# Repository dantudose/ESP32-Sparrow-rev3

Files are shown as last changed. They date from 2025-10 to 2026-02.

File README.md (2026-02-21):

# ESP32-Sparrow rev.3 Board

The ESP32 Sparrow board is an IoT device designed for projects that require low battery consumption. It is built around the ESP32-C6 module, which features WiFi, Bluetooth, Zigbee and Thread communication.

## Pinout

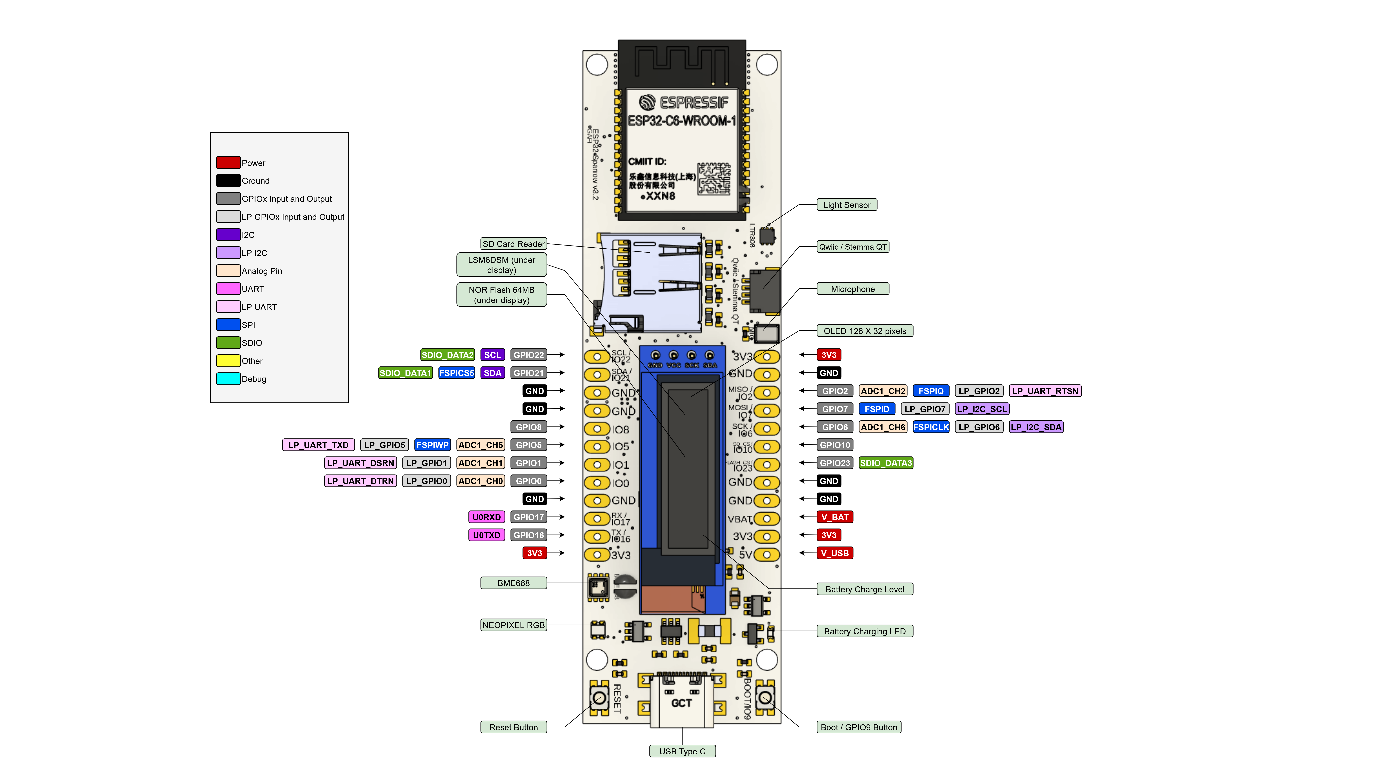
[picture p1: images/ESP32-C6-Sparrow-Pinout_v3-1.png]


## Components

- **Display:** 0.91" SSD1306 128x32 OLED (I2C)
- **Memory:** 
    - **Flash:** W25Q512JVEIQ - 64 MB Flash memory (SPI)
    - **SD card** slot for external storage (SPI)
- **Sensors:** 
    - **BME688**  - Temperature, humidity, pressure, and air quality sensor (I2C)
    - **SLSM6DSL** - 3-axis accelerometer and gyroscope (I2C)
    - **LTR303** - Ambient light sensor (I2C)
- **Microphone:** ICS-43434 - High-quality digital microphone (I2S)
- **LED:** WS2812B2020 - Neopixel RGB LED (GPIO)
- **Communication:** PRT-14417 - Qwiic/Stemma QT connector (I2C)
- **Voltage Supervisor:** BD5229G-TR - Shuts down microcontroller below 2.9V
- **Battery Level:** MAX17048 - Measures battery voltage (I2C)
- **USB C** connector for programming/charging
- **Power:** 18650 Battery - Holder on the back

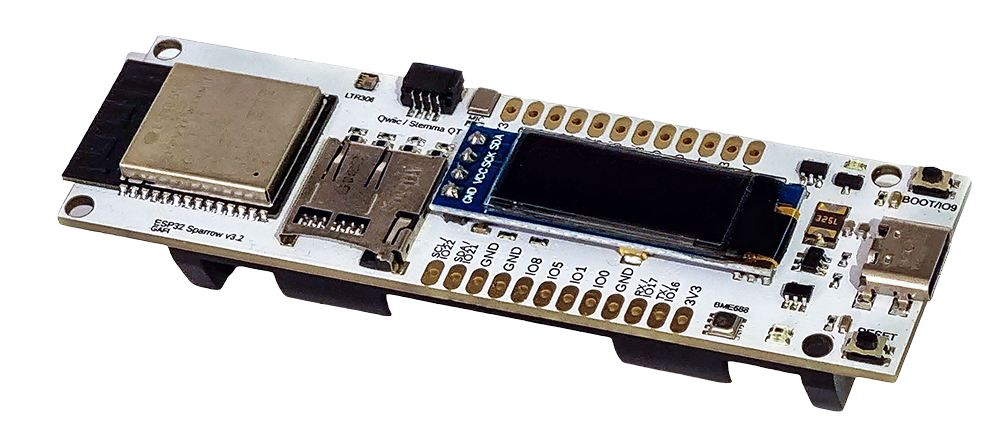
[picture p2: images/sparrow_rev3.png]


## Repository Contents
* **/hardware** - Fusion360 design files (.brd, .sch) and .pdf schematic
* **/images** - Pinout and board images
* **/software** - Code examples
    * **/arduino-ide** - Simple Arduino project
    * **/platformio** - Test project for PlatformIO
    * **/zephyr** - Test project for Zephyr OS

## Pins for each component

**1. MicroSD Card Holder (SPI)**

| PIN NAME | GPIO Pin |
|---|---|
| SD_CS | GPIO10 |
| MOSI | GPIO7 |
| MISO | GPIO2 |
| SCK | GPIO6 |

**2. NOR Flash (SPI)**

| PIN NAME | GPIO Pin |
|---|---|
| FLASH_CS | GPIO23 |
| MOSI | GPIO7 |
| MISO | GPIO2 |
| SCK | GPIO6 |

**3. I2C Sensors**

| PIN NAME | GPIO Pin |
|---|---|
| SCL | GPIO22 |
| SDA | GPIO21 |

**4. I2C Bus Addresses**

| CHIP | Address |
|---|---|
| LSM6DSL | 0x6A |
| BME680  | 0x76 |
| LTR303  | 0x29 |

**5. Neopixel RGB LED**

| PIN NAME | GPIO Pin |
|---|---|
| NEOPIXEL | GPIO3 |

**6. Microphone ICS-43434 (I2S)**

| PIN NAME | GPIO Pin |
|---|---|
| MIC_WS | GPIO20 |
| MIC_SCK  | GPIO18 |
| MIC_SD | GPIO19 |

**7. Battery Charge Level MAX17048**

| PIN NAME | GPIO Pin |
|---|---|
| INT_VLT  | GPIO4 |

**8. Other pins**

| PIN NAME | GPIO Pin |
|---|---|
| IO / BOOT Button | GPIO9 |
| UART_TX | GPIO16 |
| UART_RX | GPIO17 |
| Accelerometer Interrupt| GPIO11 |
| LTR303 Interrupt | GPIO15 |

License Information
-------------------

This product is _**open source**_! 

Please review the LICENSE file for license information. 

Distributed as-is; no warranty is given.

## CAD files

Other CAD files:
hardware/ESP32_C6_Sparrow.f3d

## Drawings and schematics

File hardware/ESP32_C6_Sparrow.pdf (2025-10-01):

# I2C OLED Display 128x32

D2

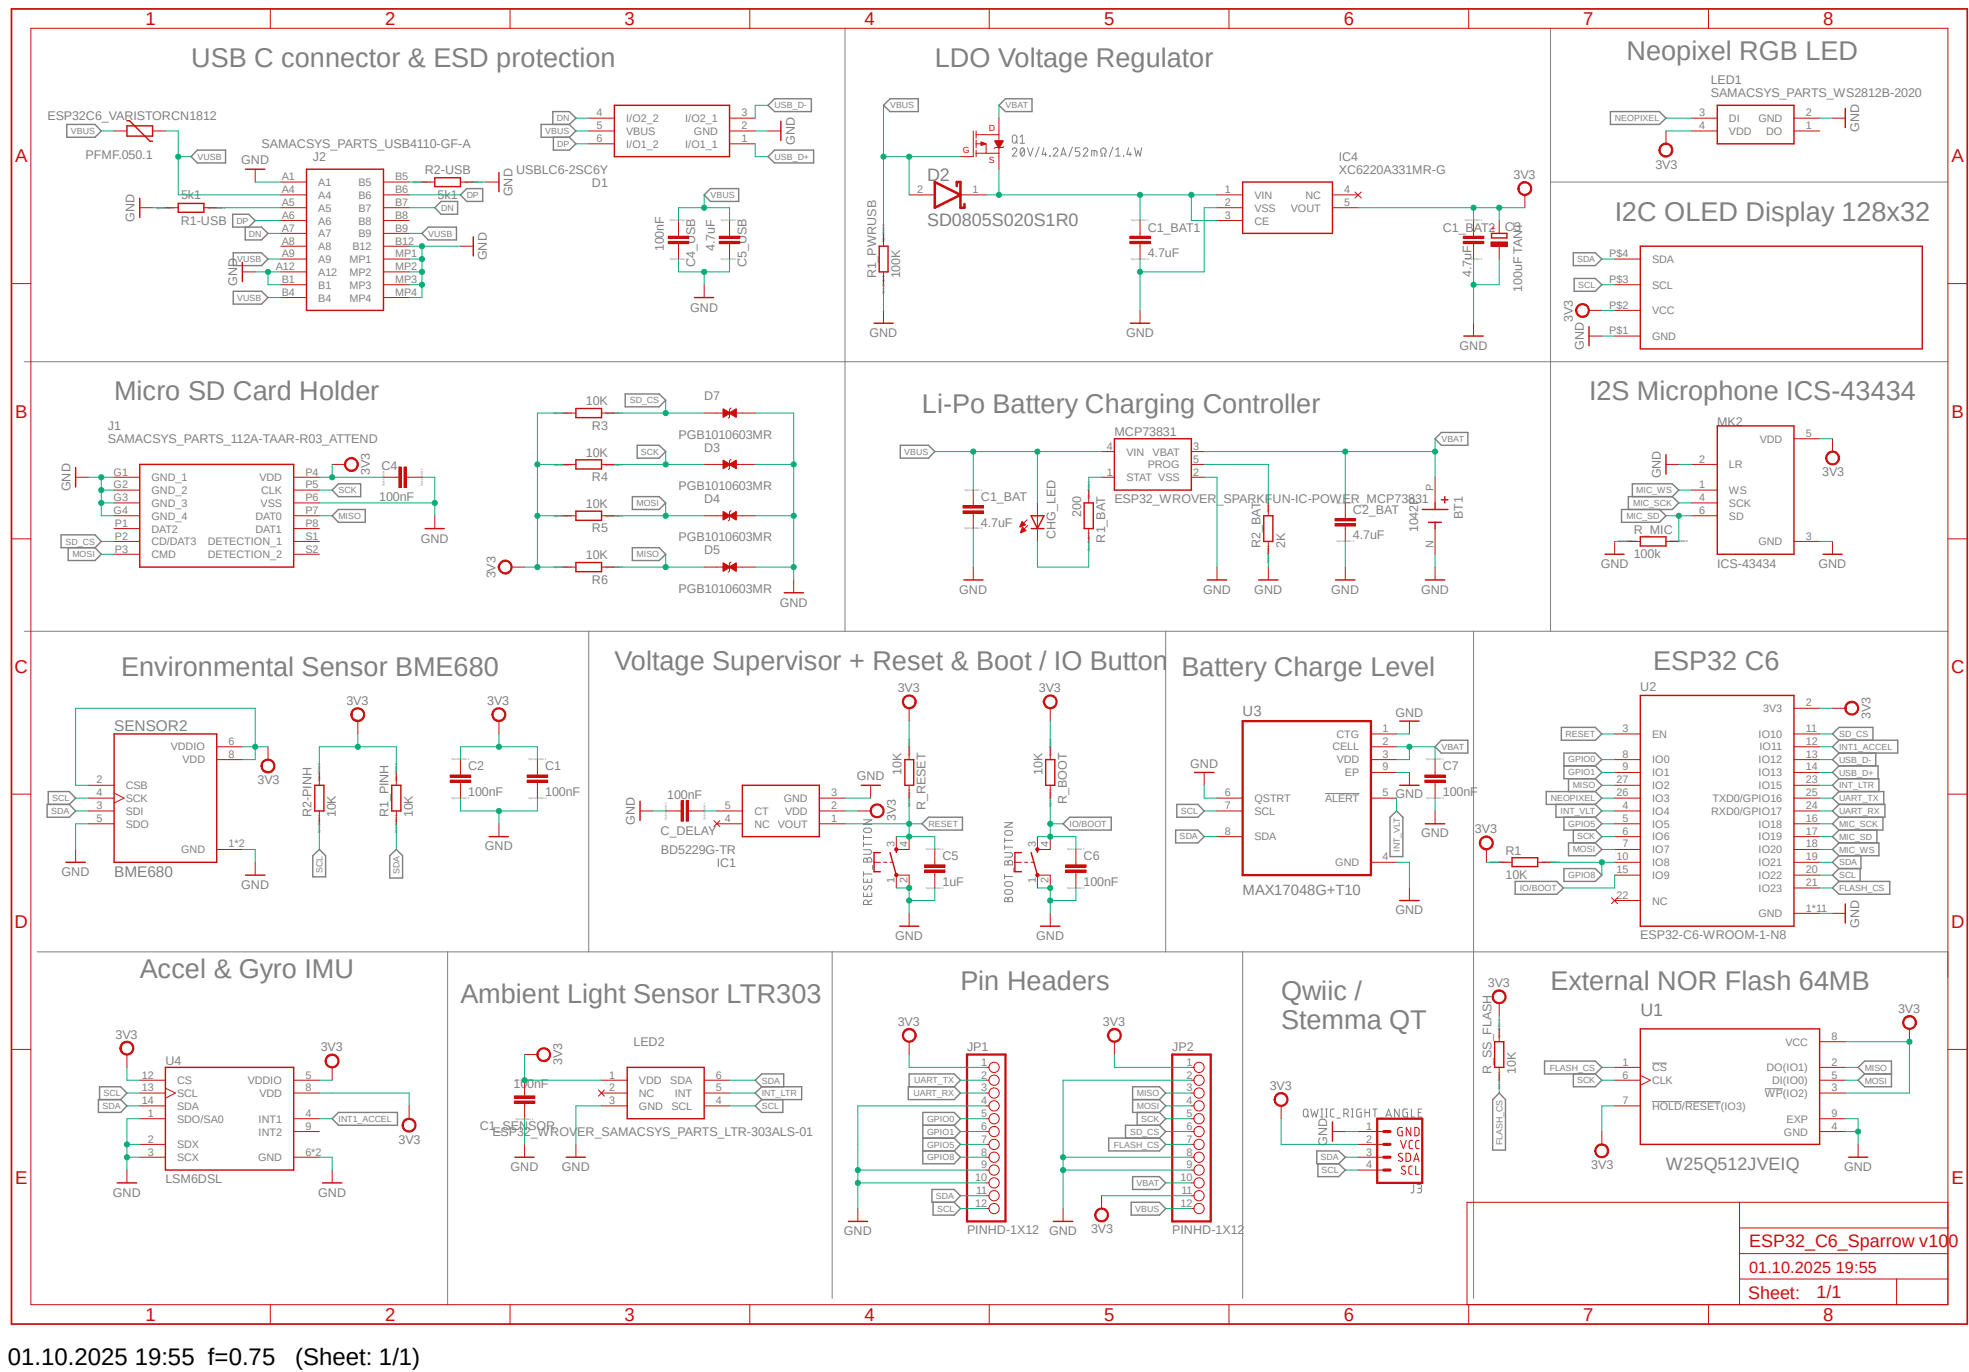
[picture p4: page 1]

USB C connector & ESD protection | LDO Voltage Regulator | Neopixel RGB LED LED1 SAMACSYS_PARTS_WS2812B-2020

Micro SD Card Holder

Li-Po Battery Charging Controller

Voltage Supervisor + Reset & Boot / IO Button

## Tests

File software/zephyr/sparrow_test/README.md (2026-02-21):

# Sparrow Test Project (Zephyr)

Minimal Zephyr application intended for the Sparrow v3.2 board (ESP32-C6-WROOM-1-N4, 4MB Flash).

## Build & Flash

From this folder:

```sh
west build -b esp32c6_devkitc/esp32c6/hpcore -p auto .
west flash -d build --runner esp32
```

## Connect over USB
```sh
screen /dev/cu.usbmodem1101 115200
```

## One-shot dev script

There is a helper script to clean, build, flash the LittleFS image, flash
firmware, and open a serial terminal:

```sh
./scripts/dev_flash.sh /dev/cu.usbmodem1101
```

Override the board with `BOARD=...` if needed.

## LittleFS assets

This app serves the all file assets directly into the LittleFS partition in the ESP32C6 internal Flash.

Build the image (requires `mklittlefs` in your PATH, run >brew install mklittlefs):

```sh
west build -t littlefs_image
```

Flash the image (overwrites `/lfs` contents, including logs):

```sh
ESPTOOL_PORT=/dev/tty.usbmodemXXXX python3 scripts/flash_littlefs_image.py --build-dir build
```

## Startup script

Files under `lfs/` are copied to the LittleFS root. If `lfs/startup.txt` is
present, the app executes each non-empty line as a shell command at boot.

Example `lfs/startup.txt`:

```txt
net iface up 1
wifi connect -s "WIFI_AP" -p "WIFI_PASSWORD" -k 1 -i 1
```

## Boot log

Boot and startup script events are logged to `/lfs/logs/boot.log`. You can read
it from the shell:

```sh
fs cat /lfs/logs/boot.log
```

## Features

This application includes a rich set of features for interacting with the Sparrow v3.2 hardware.

- **Peripherals**: Drivers and shell commands for the onboard OLED display, BME680, LSM6DSL, LTR303, MAX17048 sensors, and Neopixel.
- **Connectivity**: WiFi station mode with network time (NTP) synchronization.
- **Storage**: LittleFS filesystem on the internal flash for configuration, web assets, and data logging.
- **Remote Access**: A web-based UI and a comprehensive serial shell for control and diagnostics.
- **Automation**: A startup script (`/lfs/startup.txt`) can be used to run shell commands on boot.

## Peripherals

### OLED Display

The monochrome OLED display can be controlled via the `oled` shell command. It can display text, status information, and images.

- **Show status**: `oled status`
- **Show info screen**: `oled info 5` (updates every 5 seconds)
- **Turn display on/off**: `oled on`, `oled off`
- **Print text**: `oled print 0 0 "Hello"`
- **Draw a PBM image**: `oled bmp bitmaps/smiley.pbm`

The info screen provides a summary of the device status, including time, IP address, and sensor readings.

### Sensors

The application supports several onboard sensors, each with its own set of shell commands for configuration and data logging.

- **BME680 (Temp/Humidity/Pressure/Gas)**: `bme` command.
  - `bme read`: Read current sensor values.
  - `bme log start 30`: Start logging data every 30 seconds to `/lfs/logs/bme.csv`.
- **LSM6DSL (Accelerometer/Gyro)**: `lsm6dsl` command.
  - `lsm6dsl read`: Read current sensor values.
  - `lsm6dsl log start`: Start logging data.
- **LTR303 (Ambient Light)**: `ltr` command.
  - `ltr read`: Read current light sensor values (lux).
  - `ltr log start`: Start logging data.
- **MAX17048 (Fuel Gauge)**: `max` command.
  - `max read`: Read battery voltage and state of charge.
  - `max log start`: Start logging battery status.

### Neopixel

The RGB Neopixel can be controlled with the `neopixel` command.

- **Set color**: `neopixel set_rgb 255 0 0` (Red)
- **Set brightness**: `neopixel set_hsv 0 255 50`
- **Turn off**: `neopixel off`

## Web Interface

The device runs a web server that provides a user interface for monitoring the device.

1. Connect the device to your WiFi network:
   ```sh
   wifi connect -s "YOUR_WIFI_AP" -p "YOUR_WIFI_PASSWORD"
   ```
2. Get the device's IP address:
   ```sh
   net iface
   ```
3. Open a web browser and navigate to `http://<device-ip>/`.

The web interface is served from the `/lfs/web/` directory. You can also retrieve sensor logs, e.g., `http://<device-ip>/bme_log`.

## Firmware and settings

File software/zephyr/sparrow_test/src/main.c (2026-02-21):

#include <ctype.h>
#include <errno.h>
#include <stdbool.h>
#include <stdlib.h>
#include <string.h>
#include <zephyr/device.h>
#include <zephyr/devicetree.h>
#include <zephyr/drivers/gpio.h>
#include <zephyr/kernel.h>
#include <zephyr/shell/shell.h>
#include <zephyr/shell/shell_uart.h>
#include <zephyr/storage/flash_map.h>
#include <zephyr/sys/printk.h>
#include <zephyr/sys/util.h>

#include "app_paths.h"
#include "boot_log.h"
#include "fs_utils.h"
#include "net_time.h"
#include "sensors.h"
#include "startup.h"

int main(void)
{
	int rc;

	printk("Zephyr console ready (ESP32-C6 Sparrow).\n");
	time_init();
	rc = mount_littlefs();
	if (rc == 0) {
		boot_log_init();
		boot_log_write("boot: littlefs mounted at %s", LITTLEFS_MOUNT_POINT);
		boot_diag_start();
	} else {
		printk("Boot: LittleFS unavailable, skipping HTTP server\n");
	}
	net_set_default_wifi();
	net_ipv4_diag_init();
	net_log_diagnostics("boot");
	time_sync_start();
	sensors_init();
	startup_script_start();

	while (true) {
		k_sleep(K_SECONDS(1));
	}

	return 0;
}

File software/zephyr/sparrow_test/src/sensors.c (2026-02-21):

#include "sensors.h"

#include <errno.h>
#include <inttypes.h>
#include <stdbool.h>
#include <stdlib.h>
#include <string.h>
#include <zephyr/devicetree.h>
#include <zephyr/drivers/fuel_gauge.h>
#include <zephyr/drivers/gpio.h>
#include <zephyr/drivers/i2c.h>
#include <zephyr/drivers/sensor.h>
#include <zephyr/fs/fs.h>
#include <zephyr/kernel.h>
#include <zephyr/shell/shell.h>
#include <zephyr/sys/atomic.h>
#include <zephyr/sys/printk.h>
#include <zephyr/sys/util.h>

#include "app_paths.h"
#include "boot_log.h"
#include "fs_utils.h"
#include "net_time.h"

#define BME680_NODE DT_NODELABEL(bme688)
#define LSM6DSL_NODE DT_NODELABEL(lsm6dsl)
#define LSM6DSL_DEFAULT_ACCEL_ODR_HZ 104
#define LSM6DSL_DEFAULT_GYRO_ODR_HZ 104
#define LSM6DSL_DEFAULT_ACCEL_RANGE_G 2
#define LSM6DSL_DEFAULT_GYRO_RANGE_DPS 250
#if DT_HAS_COMPAT_STATUS_OKAY(maxim_max17048)
#define MAX17048_NODE DT_INST(0, maxim_max17048)
#if DT_NODE_EXISTS(DT_NODELABEL(max17048_alert))
#define MAX17048_ALERT_NODE DT_NODELABEL(max17048_alert)
#define MAX17048_ALERT_AVAILABLE 1
#else
#define MAX17048_ALERT_AVAILABLE 0
#endif
#else
#define MAX17048_ALERT_AVAILABLE 0
#endif

#define BME_LOG_THREAD_STACK_SIZE 3072
#define BME_LOG_THREAD_PRIORITY 5
#define BME_LOG_DEFAULT_INTERVAL_S 5
#define LTR_LOG_THREAD_STACK_SIZE 3072
#define LTR_LOG_THREAD_PRIORITY 5
#define LTR_LOG_DEFAULT_INTERVAL_S 5
#define LSM6DSL_LOG_THREAD_STACK_SIZE 3072
#define LSM6DSL_LOG_THREAD_PRIORITY 5
#define LSM6DSL_LOG_DEFAULT_INTERVAL_S 5
#define MAX17048_LOG_THREAD_STACK_SIZE 3072
#define MAX17048_LOG_THREAD_PRIORITY 5
#define MAX17048_LOG_DEFAULT_INTERVAL_S 5

#define BME_LOG_EVENT_START BIT(0)
#define BME_LOG_EVENT_STOP BIT(1)
#define BME_LOG_EVENT_INTERVAL BIT(2)
#define LTR_LOG_EVENT_START BIT(0)
#define LTR_LOG_EVENT_STOP BIT(1)
#define LTR_LOG_EVENT_INTERVAL BIT(2)
#define LSM6DSL_LOG_EVENT_START BIT(0)
#define LSM6DSL_LOG_EVENT_STOP BIT(1)
#define LSM6DSL_LOG_EVENT_INTERVAL BIT(2)
#define MAX17048_LOG_EVENT_START BIT(0)
#define MAX17048_LOG_EVENT_STOP BIT(1)
#define MAX17048_LOG_EVENT_INTERVAL BIT(2)

const struct device *const bme680 = DEVICE_DT_GET(BME680_NODE);
static const struct i2c_dt_spec bme680_i2c = I2C_DT_SPEC_GET(BME680_NODE);
static const struct device *const lsm6dsl_dev = DEVICE_DT_GET(LSM6DSL_NODE);
static const struct gpio_dt_spec lsm6dsl_int_gpio =
	GPIO_DT_SPEC_GET_OR(LSM6DSL_NODE, irq_gpios, {0});
static struct gpio_callback lsm6dsl_int_cb;
static atomic_t lsm6dsl_int_count = ATOMIC_INIT(0);
static bool lsm6dsl_int_enabled;
static bool lsm6dsl_int_callback_added;
static int lsm6dsl_accel_odr_hz = LSM6DSL_DEFAULT_ACCEL_ODR_HZ;
static int lsm6dsl_gyro_odr_hz = LSM6DSL_DEFAULT_GYRO_ODR_HZ;
static int lsm6dsl_accel_range_g = LSM6DSL_DEFAULT_ACCEL_RANGE_G;
static int lsm6dsl_gyro_range_dps = LSM6DSL_DEFAULT_GYRO_RANGE_DPS;
static bool lsm6dsl_powered = true;
static atomic_t bme_log_running = ATOMIC_INIT(0);
static atomic_t bme_log_interval_s = ATOMIC_INIT(BME_LOG_DEFAULT_INTERVAL_S);
static struct k_thread bme_log_thread;
static K_THREAD_STACK_DEFINE(bme_log_stack, BME_LOG_THREAD_STACK_SIZE);
static K_EVENT_DEFINE(bme_log_event);
static char bme_log_path[BME_LOG_PATH_MAX] = BME_LOG_PATH_DEFAULT;
static struct k_mutex bme_log_path_lock;
static atomic_t ltr_log_running = ATOMIC_INIT(0);
static atomic_t ltr_log_interval_s = ATOMIC_INIT(LTR_LOG_DEFAULT_INTERVAL_S);
static struct k_thread ltr_log_thread;
static K_THREAD_STACK_DEFINE(ltr_log_stack, LTR_LOG_THREAD_STACK_SIZE);
static K_EVENT_DEFINE(ltr_log_event);
static char ltr_log_path[LTR_LOG_PATH_MAX] = LTR_LOG_PATH_DEFAULT;
static struct k_mutex ltr_log_path_lock;
static atomic_t lsm6dsl_log_running = ATOMIC_INIT(0);
static atomic_t lsm6dsl_log_interval_s = ATOMIC_INIT(LSM6DSL_LOG_DEFAULT_INTERVAL_S);
static struct k_thread lsm6dsl_log_thread;
static K_THREAD_STACK_DEFINE(lsm6dsl_log_stack, LSM6DSL_LOG_THREAD_STACK_SIZE);
static K_EVENT_DEFINE(lsm6dsl_log_event);
static char lsm6dsl_log_path[LSM6DSL_LOG_PATH_MAX] = LSM6DSL_LOG_PATH_DEFAULT;
static struct k_mutex lsm6dsl_log_path_lock;
#if DT_HAS_COMPAT_STATUS_OKAY(maxim_max17048)
static atomic_t max17048_log_running = ATOMIC_INIT(0);
static atomic_t max17048_log_interval_s = ATOMIC_INIT(MAX17048_LOG_DEFAULT_INTERVAL_S);
static struct k_thread max17048_log_thread;
static K_THREAD_STACK_DEFINE(max17048_log_stack, MAX17048_LOG_THREAD_STACK_SIZE);
static K_EVENT_DEFINE(max17048_log_event);
static char max17048_log_path[MAX17048_LOG_PATH_MAX] = MAX17048_LOG_PATH_DEFAULT;
static struct k_mutex max17048_log_path_lock;
static const struct device *const max17048_dev = DEVICE_DT_GET(MAX17048_NODE);
#if MAX17048_ALERT_AVAILABLE
static const struct gpio_dt_spec max17048_alert = GPIO_DT_SPEC_GET(MAX17048_ALERT_NODE, gpios);
static struct gpio_callback max17048_alert_cb;
static atomic_t max17048_alert_count = ATOMIC_INIT(0);
#endif
#endif

void bme_log_get_path(char *buf, size_t len)
{
	if (!buf || len == 0U) {
		return;
	}

	k_mutex_lock(&bme_log_path_lock, K_FOREVER);
	snprintk(buf, len, "%s", bme_log_path);
	k_mutex_unlock(&bme_log_path_lock);
}

static int bme_log_set_path(const char *path)
{
	char tmp[BME_LOG_PATH_MAX];
	const char *use_path = path;
	size_t len;

	if (!path || path[0] == '\0') {
		return -EINVAL;
	}

	if (path[0] != '/') {
		int rc = snprintk(tmp, sizeof(tmp), "%s/%s", BME_LOG_DIR, path);
		if (rc < 0 || rc >= (int)sizeof(tmp)) {
			return -ENAMETOOLONG;
		}
		use_path = tmp;
	}

	if (strncmp(use_path, LITTLEFS_MOUNT_POINT "/", strlen(LITTLEFS_MOUNT_POINT) + 1) != 0) {
		return -EINVAL;
	}

	len = strlen(use_path);
	if (len >= sizeof(bme_log_path)) {
		return -ENAMETOOLONG;
	}

	k_mutex_lock(&bme_log_path_lock, K_FOREVER);
	memcpy(bme_log_path, use_path, len + 1);
	k_mutex_unlock(&bme_log_path_lock);

	return 0;
}

static int ensure_bme_log_path(void)
{
	char path[BME_LOG_PATH_MAX];

	bme_log_get_path(path, sizeof(path));
	return ensure_dir_tree_for_file(path);
}

static void ltr_log_get_path(char *buf, size_t len)
{
	if (!buf || len == 0U) {
		return;
	}

	k_mutex_lock(&ltr_log_path_lock, K_FOREVER);
	snprintk(buf, len, "%s", ltr_log_path);
	k_mutex_unlock(&ltr_log_path_lock);
}

static int ltr_log_set_path(const char *path)
{
	char tmp[LTR_LOG_PATH_MAX];
	const char *use_path = path;
	size_t len;

	if (!path || path[0] == '\0') {
		return -EINVAL;
	}

	if (path[0] != '/') {
		int rc = snprintk(tmp, sizeof(tmp), "%s/%s", LTR_LOG_DIR, path);
		if (rc < 0 || rc >= (int)sizeof(tmp)) {
			return -ENAMETOOLONG;
		}
		use_path = tmp;
	}

	if (strncmp(use_path, LITTLEFS_MOUNT_POINT "/", strlen(LITTLEFS_MOUNT_POINT) + 1) != 0) {
		return -EINVAL;
	}

	len = strlen(use_path);
	if (len >= sizeof(ltr_log_path)) {
		return -ENAMETOOLONG;
	}

	k_mutex_lock(&ltr_log_path_lock, K_FOREVER);
	memcpy(ltr_log_path, use_path, len + 1);
	k_mutex_unlock(&ltr_log_path_lock);

	return 0;
}
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

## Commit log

2025-10-01 Updated hardware files, added pdf
    [ESP32_C6_Sparrow.f3d]
2026-02-21 Changes to be committed: new file: .DS_Store new file: software/.DS_Store new file: software/zephyr/sparrow_test/.DS_Store new file: software/zephyr/sparrow_test/CMakeLists.txt new file: software/zep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
